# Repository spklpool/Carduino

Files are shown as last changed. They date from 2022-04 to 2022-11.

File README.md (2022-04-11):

# Carduino

This repository contains the source code for the Carduino library for Arduino IDE as well as design files for the electronics and the 3d printed enclosure for the Carduino device.  Each of these 3 components will be desctibed separately below.  More information about Carduino can be found at https://carduino.co

Everything you need to build a Carduino is in this repository if you have the necessary equipment.  If you are so inclined, you scan shop around for all the parts and build one yourself using the information you find in here.  You can also order a kit with all the electronic parts from our store at
https://www.tindie.com/stores/Sparkle/

There, you can also order one fully assembled and tested, including the 3d printed enclosure and a USB cable for close to the same price it would cost you to buy all the individual parts and the shipping costs.  Also, buying from our store helps support the continuing development of the project.  We have other things in the works you might like if you're interested in Cardano and electronics.

## Arduino library
The Arduino IDE can be downloaded here:
https://www.arduino.cc/en/software
The files that make up the library are under the src folder for reference if you want to look at the code.  To use it though, you'll want to install it as a library in the IDE.  Instructions for installing the library and everything else you need to program your Carduino can be found in this tutorial video:
https://www.youtube.com/watch?v=BPkC6jxjeJc&t=7s

## PCB design files
The PCB is designed using Eagle.  It meets the criteria for being edited using the free edition for personal use, which can be downloaded here:
https://www.autodesk.ca/en/products/eagle/free-download
The PCB design files can be found in the eagle folder.
The parts list with recommended manufacturer part numbers is available in the [parts file](eagle/parts.md)

## Enclosure 3d model
The enclosure was designed with TinkerCad.  Unfortunately, TimcarCad does not support saving the native files, but the exported .stl files can be imported and tweaked as you wish at:
https://www.tinkercad.com/
The 3d model files can be found in the model folder.

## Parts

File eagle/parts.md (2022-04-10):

| Component | Manufacturer Part # | Count |
| --- | --- | ----- |
| USB Connector | 10118194-0011LF | 1 |
| USB to Serial | 428-203591-MG01 | 1 |
| Realtime Clock | RV-3028-C7 32.768kHz 1ppm | 1 |
| Battery Holder | BAT-HLD-012-SMT | 1 |
| Microprocessor | ATTINY804-SSF | 1 |
| Shift Register | SN74HCS596DR | 4 |
| Display LEDs | IN-P32AT5UW |  30 |
| Rx/Tx LEDs | 150080VS75000 | 2 |
| 1K Resistors | CR1206-JW-472ELF |  34 |
| 4.7 uF Capacitor | 791-0805B475M160CT | 1 |

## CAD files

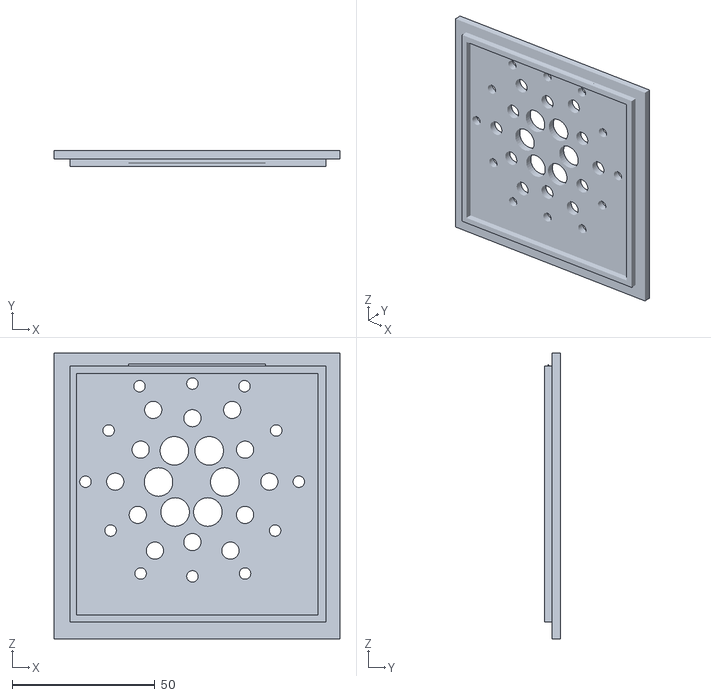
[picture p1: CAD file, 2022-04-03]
model/CarduinoFace.stl
100.0 x 5.70 x 100.0

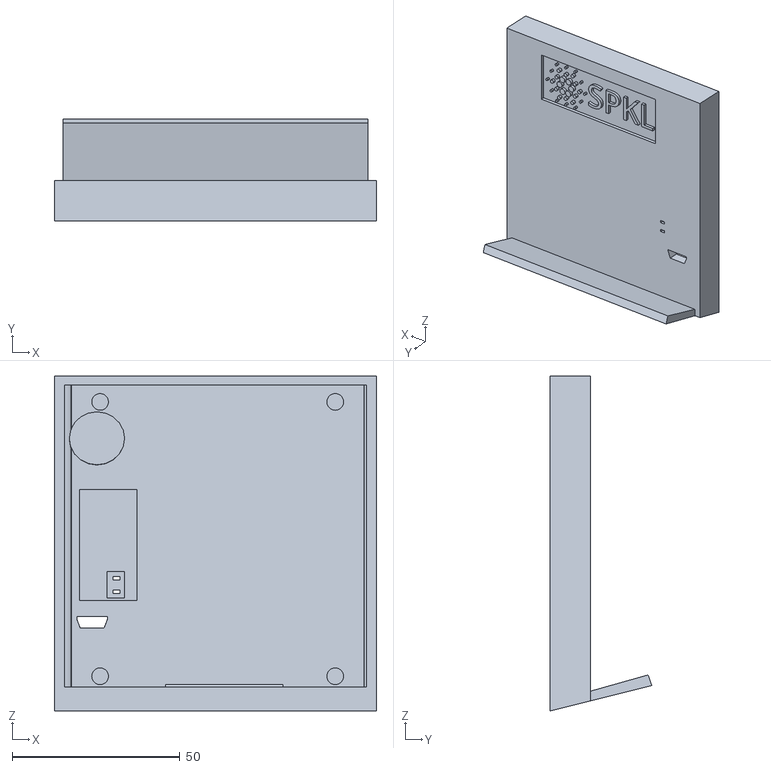
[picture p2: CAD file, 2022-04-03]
model/CarduinoBackWithLogo.stl
96.0 x 30.3 x 99.8

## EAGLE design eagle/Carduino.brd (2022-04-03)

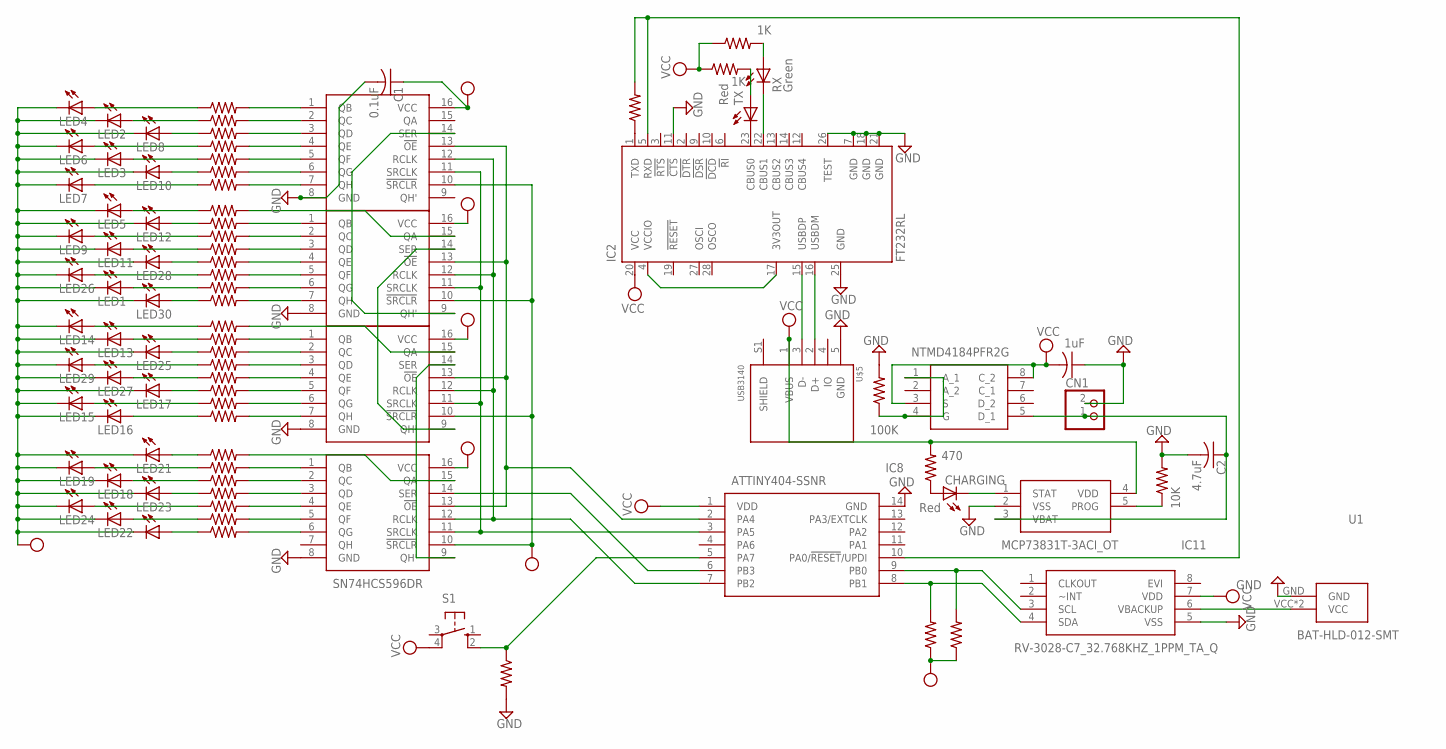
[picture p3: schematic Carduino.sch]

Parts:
C1: 0.1uF; C1206
C2: 4.7uF; C1206
C3: 1uF; C1206
CHARGING: Red; CHIP-LED0805
CN1: JST_2PIN-SMT-RA; JST-PH-2-SMT-RA
IC2: FT232RL; SSOP28
IC3, IC4, IC5, IC6: SN74HCS596DR; SOIC127P600X175-16N
IC7: NTMD4184PFR2G; SOIC127P600X175-8N
IC8: ATTINY404-SSNR; SOIC127P600X175-14N
IC9: MCP73831T-3ACI_OT; SOT95P270X145-5N
IC11: RV-3028-C7_32.768KHZ_1PPM_TA_Q; RV3028C732768KHZ1PPMTAQC
LED1, LED2, LED3, LED4, LED5, LED6, LED7, LED8, LED9, LED10, LED11, LED12, LED13, LED14, LED15, LED16, LED17, LED18, LED19, LED20, LED21, LED22, LED23, LED24, LED25, LED26, LED27, LED28, LED29, LED30: LUXEON2835L128-1890NA3500001; LUXEON2835
R1, R16: 470; R0805
R2, R3, R7, R8, R9, R10, R11, R12, R13, R14, R15, R17, R18, R19, R20, R31, R32, R33, R34, R35, R36, R37, R38, R39, R40, R41, R42, R43, R44, R45, R46, R47: 1K; R0805
R4, R5, R6: 4.7K; R0805
R21: 100K; R0805
R22: 10K; R0805
RX: Green; CHIP-LED0805
S1: 40-XX-ROUND; B3F-40XX-ROUND
TX: Red; CHIP-LED0805
U1: BAT-HLD-012-SMT; BATHLD012SMT
U$5: USB3140; USB3140-30-0170-0-C

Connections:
GND: C1.2, C2.2, C3.1, CN1.2 (1), IC2.7 (GND), IC2.11 (!CTS), IC2.18 (GND), IC2.21 (GND), IC2.25 (GND), IC2.26 (TEST), IC3.8 (GND), IC4.8 (GND), IC5.8 (GND), IC6.8 (GND), IC8.14 (GND), IC9.2 (VSS), IC11.5 (VSS), R6.2, R21.2, R22.2, U1.GND, U$5.5 (GND)
unnamed: LED4.ANODE (A), R15.1
unnamed: LED2.ANODE (A), R14.1
unnamed: LED8.ANODE (A), R13.1
unnamed: LED6.ANODE (A), R12.1
unnamed: LED3.ANODE (A), R11.1
unnamed: LED12.ANODE (A), R7.1
unnamed: LED7.ANODE (A), R9.1
unnamed: LED5.ANODE (A), R8.1
unnamed: LED10.ANODE (A), R10.1
unnamed: LED9.ANODE (A), R17.1
unnamed: LED11.ANODE (A), R18.1
unnamed: LED28.ANODE (A), R19.1
unnamed: LED26.ANODE (A), R20.1
unnamed: LED1.ANODE (A), R31.1
unnamed: LED30.ANODE (A), R32.1
unnamed: LED14.ANODE (A), R33.1
unnamed: LED13.ANODE (A), R34.1
unnamed: LED25.ANODE (A), R35.1
unnamed: LED29.ANODE (A), R36.1
unnamed: LED27.ANODE (A), R37.1
unnamed: LED17.ANODE (A), R38.1
unnamed: LED15.ANODE (A), R39.1
unnamed: LED16.ANODE (A), R40.1
unnamed: LED21.ANODE (A), R41.1
unnamed: LED19.ANODE (A), R42.1
unnamed: LED18.ANODE (A), R43.1
unnamed: LED23.ANODE (A), R44.1
unnamed: LED24.ANODE (A), R45.1
unnamed: LED22.ANODE (A), R46.1
unnamed: LED20.ANODE (A), R47.1
unnamed: IC8.8 (PB1), IC11.4 (SDA), R4.2
unnamed: IC8.9 (PB0), IC11.3 (SCL), R5.2
unnamed: IC11.6 (VBACKUP), U1.VCC, U1.VCC2 (VCC)
unnamed: IC8.5 (PA7), R6.1, S1.2 (S1)
unnamed: IC3.13 (!OE), IC4.13 (!OE), IC5.13 (!OE), IC6.13 (!OE), IC8.2 (PA4)
unnamed: IC7.1 (A_1), IC7.4 (G), R21.1
unnamed: IC9.5 (PROG), R22.1
unnamed: C2.1, CN1.1 (2), IC7.5 (D_1), IC9.3 (VBAT)
unnamed: CHARGING.C, IC9.1 (STAT)
unnamed: CHARGING.A, R16.1
unnamed: IC3.1 (QB), R15.2
unnamed: IC3.2 (QC), R14.2
unnamed: IC3.3 (QD), R13.2
unnamed: IC3.4 (QE), R12.2
unnamed: IC3.5 (QF), R11.2
unnamed: IC3.6 (QG), R10.2
unnamed: IC3.7 (QH), R9.2
unnamed: IC4.15 (QA), R8.2
unnamed: IC4.1 (QB), R7.2
unnamed: IC4.2 (QC), R17.2
unnamed: IC4.3 (QD), R18.2
unnamed: IC4.4 (QE), R19.2
unnamed: IC4.5 (QF), R20.2
unnamed: IC4.6 (QG), R31.2
unnamed: IC4.7 (QH), R32.2
unnamed: IC5.15 (QA), R33.2
unnamed: IC5.1 (QB), R34.2
unnamed: IC5.2 (QC), R35.2
unnamed: IC5.3 (QD), R36.2
unnamed: IC5.4 (QE), R37.2
unnamed: IC5.5 (QF), R38.2
unnamed: IC5.6 (QG), R39.2
unnamed: IC5.7 (QH), R40.2
unnamed: IC6.6 (QG), R47.2
unnamed: IC6.5 (QF), R46.2
unnamed: IC6.4 (QE), R45.2
unnamed: IC6.3 (QD), R44.2
unnamed: IC6.2 (QC), R43.2
unnamed: IC6.1 (QB), R42.2
unnamed: IC6.15 (QA), R41.2
unnamed: IC5.14 (SER), IC6.9 (QH')
unnamed: IC4.14 (SER), IC5.9 (QH')
unnamed: IC3.14 (SER), IC4.9 (QH')
unnamed: IC3.11 (SRCLK), IC4.11 (SRCLK), IC5.11 (SRCLK), IC6.11 (SRCLK), IC8.3 (PA5)
unnamed: IC3.12 (RCLK), IC4.12 (RCLK), IC5.12 (RCLK), IC6.12 (RCLK), IC8.7 (PB2)
unnamed: IC6.14 (SER), IC8.6 (PB3)
unnamed: IC2.16 (USBDM), U$5.2 (D+)
unnamed: IC2.15 (USBDP), U$5.3 (D-)
unnamed: IC2.4 (VCCIO), IC2.17 (3V3OUT)
unnamed: IC2.1 (TXD), R1.1
unnamed: IC2.5 (RXD), IC8.10 (PA0/!RESET!/UPDI), R1.2
unnamed: R2.2, RX.A
unnamed: R3.2, TX.A
unnamed: IC2.23 (CBUS0), TX.C
unnamed: IC2.22 (CBUS1), RX.C
VCC: C1.1, C3.2, IC2.20 (VCC), IC3.10 (!SRCLR), IC3.16 (VCC), IC4.10 (!SRCLR), IC4.16 (VCC), IC5.10 (!SRCLR), IC5.16 (VCC), IC6.10 (!SRCLR), IC6.16 (VCC), IC7.3 (S), IC7.8 (C_2), IC8.1 (VDD), IC9.4 (VDD), IC11.7 (VDD), LED1.CATHODE (C), LED2.CATHODE (C), LED3.CATHODE (C), LED4.CATHODE (C), LED5.CATHODE (C), LED6.CATHODE (C), LED7.CATHODE (C), LED8.CATHODE (C), LED9.CATHODE (C), LED10.CATHODE (C), LED11.CATHODE (C), LED12.CATHODE (C), LED13.CATHODE (C), LED14.CATHODE (C), LED15.CATHODE (C), LED16.CATHODE (C), LED17.CATHODE (C), LED18.CATHODE (C), LED19.CATHODE (C), LED20.CATHODE (C), LED21.CATHODE (C), LED22.CATHODE (C), LED23.CATHODE (C), LED24.CATHODE (C), LED25.CATHODE (C), LED26.CATHODE (C), LED27.CATHODE (C), LED28.CATHODE (C), LED29.CATHODE (C), LED30.CATHODE (C), R2.1, R3.1, R4.1, R5.1, R16.2, S1.4 (P1), U$5.1 (VBUS)

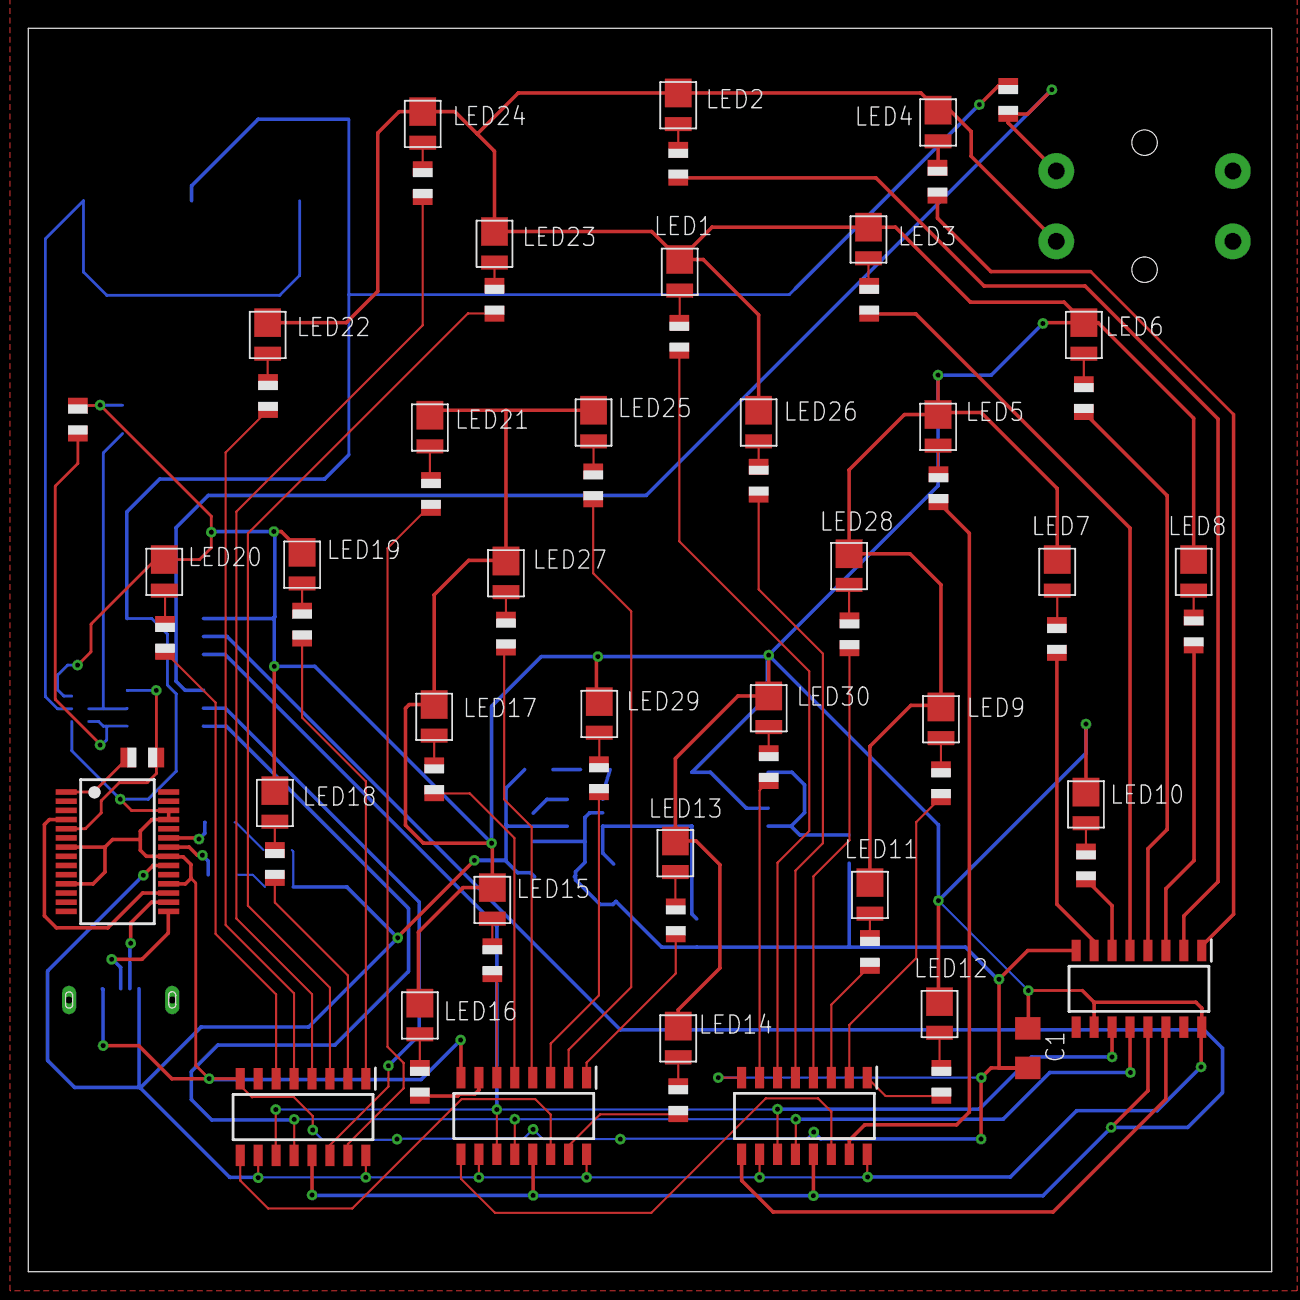
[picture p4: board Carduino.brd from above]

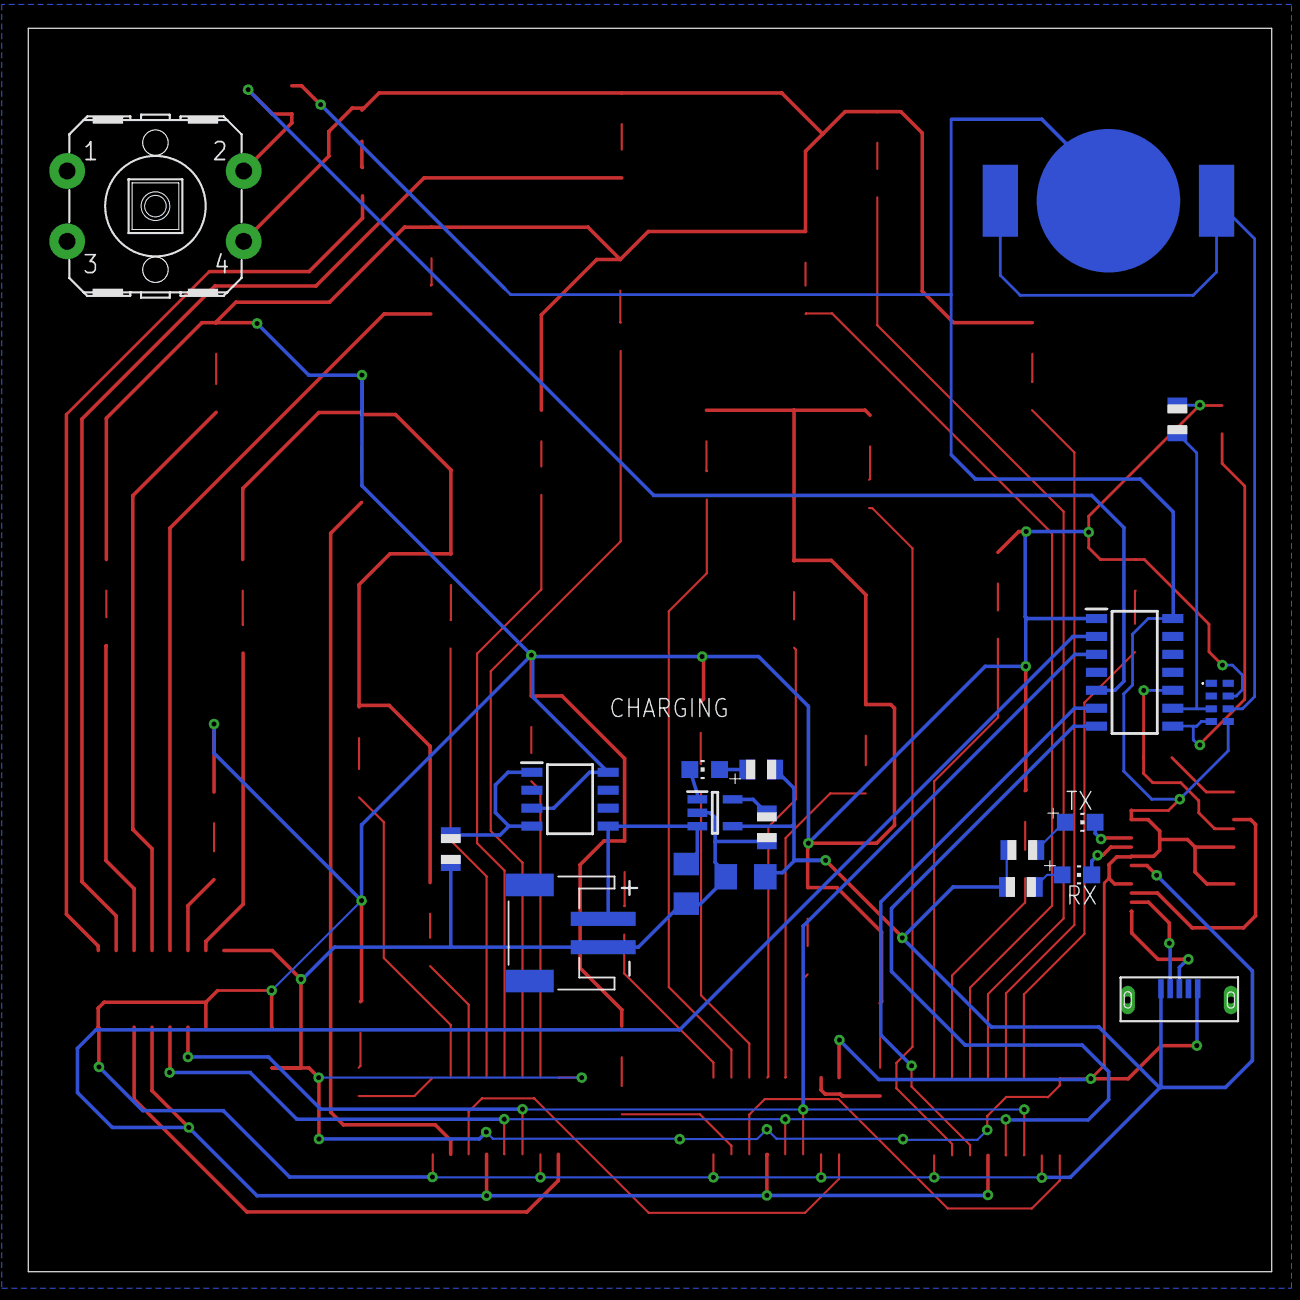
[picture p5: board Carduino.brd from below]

Board: 2 copper layers, 88.0 x 88.0 mm, 88 parts (19 on the bottom side), 87 nets.

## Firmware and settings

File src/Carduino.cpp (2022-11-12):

#include "Arduino.h"
#include "Carduino.h"

// functions copied from https://github.com/NorthernWidget/DS3231
// just took the minimal fuctionality we need for Carduino, which
// does not care about actual dates and times.  We just want a high
// precision number of seconds since a given start time to calculate
// epochs and fractions thereof.
static uint8_t bcd2bin (uint8_t val) { return val - 6 * (val >> 4); }
static const uint8_t daysInMonth [] PROGMEM = { 31,28,31,30,31,30,31,31,30,31,30,31 };
bool isleapYear(const uint8_t y) {
  if(y&3)//check if divisible by 4
    return false;
  //only check other, when first failed
  return (y % 100 || y % 400 == 0);
}
static uint16_t date2days(uint16_t y, uint8_t m, uint8_t d) {
    if (y >= 2000)
        y -= 2000;
    uint16_t days = d;
    for (uint8_t i = 1; i < m; ++i)
        days += pgm_read_byte(daysInMonth + i - 1);
    if (m > 2 && isleapYear(y))
        ++days;
    return days + DAYS_IN_YEAR * y + (y + 3) / 4 - 1;
}
static long time2long(uint16_t days, uint8_t h, uint8_t m, uint8_t s) {
    return ((days * 24L + h) * 60 + m) * 60 + s;
}
byte Carduino::decToBcd(byte val) {
  return ( (val/10*16) + (val%10) );
}
byte Carduino::bcdToDec(byte val) {
  return ( (val/16*10) + (val%16) );
}
// end of copied functions


Carduino::Carduino() {
  pinMode(clockPin, OUTPUT);
  pinMode(dataPin, OUTPUT);
  pinMode(latchPin, OUTPUT);
  pinMode(buttonPin, INPUT);
  pinMode(oePin, OUTPUT);
  Wire.begin();
}

void Carduino::init() {
  if (isRV3028Clock()) {
    if (!isRV3028Configured()) {
      RV3028Configure();
      configuringConfirmationDisplay();
    }
  }
}

void Carduino::setBrightness(byte brightness) // 0 to 255
{
  analogWrite(oePin, 255-brightness);
}

void Carduino::displayHoursAndMinutes() {
  uint16_t y;
  uint8_t m, d, hh, mm, ss;
  
  getNowFromClock(y,  m, d, hh, mm, ss);

  uint32_t hoursArray[] = { dot2, dot4, dot6, dot8, 
                            dot10, dot12, dot14, dot16,
                            dot18, dot20, dot22, dot24 };

  uint32_t minutesArray2[] = { dot1, dot3, dot5, dot7, 
                               dot9, dot11, dot13, dot15,
                               dot17, dot19, dot21, dot23 };

  uint32_t minutesArray1[] = { dot25, dot26, dot28, dot30, dot29, dot27 };
  
  displayDots(hoursArray[hh%12] & minutesArray1[mm/10] & minutesArray2[mm%10]);

// uncomment to debug on a device that supports it
//  char dateTimeString[60];
//  sprintf(dateTimeString, "hh mod 12: %i mm/10: %i mm mod 10: %i", hh%12, mm/10, mm%10);
//  Serial.println(dateTimeString);

  delay(1000);
}

void Carduino::runClock() {
  runClock(1, false);
}

void Carduino::runClock(bool middleEpochCounter) {
  runClock(1, middleEpochCounter);
}

void Carduino::runClock(uint32_t speedMultiplier) {
  runClock(speedMultiplier, false);
}

void Carduino::runClock(uint32_t speedMultiplier, bool middleEpochCounter) {
  
  const int sizeofClockarray = 30;
  uint32_t clockarray[sizeofClockarray] = { dot1, dot2, dot3, dot4, dot5, dot6, dot7, dot8,
                                            dot9, dot10, dot11, dot12, dot13, dot14, dot15, dot16,
                                            dot17, dot18, dot19, dot20, dot21, dot22, dot23, dot24,
                                            dot25, dot26, dot27, dot28, dot29, dot30 };
  for (int i=0; i<sizeofClockarray; i++) {
    if (i>0) {
      clockarray[i] = clockarray[i] & clockarray[i-1];
    } 
  }
  
  unsigned long beginingOfTimeSeconds = getSecondsAtBeginingOfTime();
  unsigned long nowSeconds = getNowFromClock() - (BEGINING_OF_TIME_UTC_OFFSET * 3600);
  unsigned long shelley_seconds = nowSeconds - beginingOfTimeSeconds;
  unsigned long seconds_in_epoch = 432000; //60*60*5*24
  unsigned long seconds_in_this_epoch = shelley_seconds % seconds_in_epoch;
  float portion_of_epoch_completed = seconds_in_this_epoch / (float)seconds_in_epoch;
  int dot = portion_of_epoch_completed * 24;
  int epochIndex = seconds_in_this_epoch % 6;

  // was overflowing dynamic memory space with an array of middle dots
  // below implementation is uglier than using an array , but it trades
  // program space (which I have) with dynamic memory space (which I don't have)
  if (epochIndex == 0) {
    displayDots(clockarray[dot] & dot25);
  } else if (epochIndex == 1) {
    displayDots(clockarray[dot] & dot25 & dot26);
  } else if (epochIndex == 2) {
    displayDots(clockarray[dot] & dot25 & dot26 & dot28);
  } else if (epochIndex == 3) {
    displayDots(clockarray[dot] & dot25 & dot26 & dot28 & dot30);
  } else if (epochIndex == 4) {
    displayDots(clockarray[dot] & dot25 & dot26 & dot28 & dot30 & dot29);
  } else if (epochIndex == 5) {
    displayDots(clockarray[dot] & dot25 & dot26 & dot28 & dot30 & dot29 & dot27);
  }
  delay(100);
}

void Carduino::teaser() {
  delay(3000);
  accelleratingClock();
  reverseClock();
  fireworks1();
  sequence4();
  fireworks2();
  fireworks2();
  sequence2(50);
  sequence3(50);
  sequence2(50);
  full();
  fadeout();
}

void Carduino::configuringConfirmationDisplay() {
  const int sizeofClockarray = 30;
  uint32_t clockarray[sizeofClockarray] = { dot1, dot2, dot3, dot4, dot5, dot6, dot7, dot8,
                                            dot9, dot10, dot11, dot12, dot13, dot14, dot15, dot16,
                                            dot17, dot18, dot19, dot20, dot21, dot22, dot23, dot24,
                                            dot25, dot26, dot27, dot28, dot29, dot30 };

  for (int i=0; i<sizeofClockarray; i++) {
    if (i>0) {
      clockarray[i] = clockarray[i] & clockarray[i-1];
    } 
  }
                                            
  for (int i=0; i<sizeofClockarray; i++) {
    displayDots(clockarray[i]);
    delay(200);
  }
}

void Carduino::sequence1() {
  const int sizeofClockarray = 30;
  uint32_t clockarray[sizeofClockarray] = { dot1, dot2, dot3, dot4, dot5, dot6, dot7, dot8,
                                            dot9, dot10, dot11, dot12, dot13, dot14, dot15, dot16,
                                            dot17, dot18, dot19, dot20, dot21, dot22, dot23, dot24,
                                            dot25, dot26, dot27, dot28, dot29, dot30 };
  for (int i=0; i<sizeofClockarray; i++) {
    displayDots(clockarray[i]);
    delay(300);
  }
}

void Carduino::sequence4() {
  const int sizeofClockarray = 30;
  uint32_t clockarray[sizeofClockarray] = { dot1, dot2, dot3, dot4, dot5, dot6, dot7, dot8,
                                            dot9, dot10, dot11, dot12, dot13, dot14, dot15, dot16,
                                            dot17, dot18, dot19, dot20, dot21, dot22, dot23, dot24,
                                            dot25, dot26, dot27, dot28, dot29, dot30 };
  for (int i=0; i<sizeofClockarray; i++) {
    displayDots(clockarray[i]);
    delay(50);
  }
}
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

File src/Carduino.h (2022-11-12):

#ifndef Carduino_h
#define Carduino_h

#include <Wire.h>

#define DS3231_ADDR                 0x68
#define RV3028_ADDR                 0x52


// These binary values are the secret sauce that makes this code simple.
// Each bit of the 32 bit entries in the array represents one
// of the output pins on one of the 4 shift registers.
// Below is a represendation of the bits grouped by the shift
// registers.  Each group of 8 bits is serialized least significant
// bit first and the shift registers are daisy chained so the right 
// most bits in the array will end up being latched on shift register
// 1 after all bits are serialized.
// 44444444333333332222222211111111

// 20 23     21 24 19 22 15 18 17 16 30 14 9  12 11 10 7 2 5 8 3 6 4

//    1      13  

#define dot0  0b11111111111111111111111111111111
#define dot1  0b11111111111111111111110111111111
#define dot2  0b11111111111111111111111111011111
#define dot3  0b11111111111111111111111111111011
#define dot4  0b11111111111111111111111110111111
#define dot5  0b11111111111111110111111111111111
#define dot6  0b11111111111111111111111111110111
#define dot7  0b11111111111111111111111111111110
#define dot8  0b11111111111111111111111111101111
#define dot9  0b11111111111111111101111111111111
#define dot10 0b11111111111111111111111111111101
#define dot11 0b11111111111111111110111111111111
#define dot12 0b11111111111111111011111111111111
#define dot13 0b11111111101111111111111111111111
#define dot14 0b11111111011111111111111111111111
#define dot15 0b11111111111111011111111111111111
#define dot16 0b11111111111111101111111111111111
#define dot17 0b11111111111110111111111111111111
#define dot18 0b11011111111111111111111111111111
#define dot19 0b10111111111111111111111111111111
#define dot20 0b11111101111111111111111111111111
#define dot21 0b01111111111111111111111111111111
#define dot22 0b11111011111111111111111111111111
#define dot23 0b11101111111111111111111111111111
#define dot24 0b11110111111111111111111111111111
#define dot25 0b11111111110111111111111111111111
#define dot26 0b11111111111111111111101111111111
#define dot27 0b11111111111101111111111111111111
#define dot28 0b11111111111111111111011111111111
#define dot29 0b11111111111011111111111111111111
#define dot30 0b11111111111111111111111011111111

#define ALLOFF 0b01111111111111111111111111111111
#define ALLON  0b00000000000000000000000000000000

#define oePin 0
#define clockPin 1
#define buttonPin 3
#define dataPin 4
#define latchPin 5

#define DAYS_IN_YEAR 365
#define CARDUINO_LED_COUNT 32
#define HOURS_TO_SECONDS_MULTIPLIER 3600
#define SECONDS_IN_DOT 18000 // 60*60*5;
#define DOTS_IN_EPOCH 24
#define MILLIS_IN_SECOND 1000
#define RESET_CYCLE_THRESHOLD 50
#define ADVANCE_CYCLE_THRESHOLD 10

// begining of time in UTC
#define BEGINING_OF_TIME_UTC_OFFSET -5
#define BEGINING_OF_TIME_HOURS 21
#define BEGINING_OF_TIME_MINUTES 45
#define BEGINING_OF_TIME_SECONDS 00
#define BEGINING_OF_TIME_DAY 3
#define BEGINING_OF_TIME_MONTH 8
#define BEGINING_OF_TIME_YEAR 20
#define SHELLY_EPOCH_OFFSET 209;

class Carduino
{
  public:
    Carduino();
    void init();
    bool isDS3231Clock();
    bool isRV3028Clock();
    void setBrightness(byte brightness);
    void displayHoursAndMinutes();
    void runClock();
    void runClock(bool middleEpochCounter);
    void runClock(uint32_t speedMultiplier);
    void runClock(uint32_t speedMultiplier, bool middleEpochCounter);
    void teaser();
    void inwardSpiral();
    void displayDots(uint32_t data);
    void setTimeToNow();
    void checkDateTime();
    void printNow();
    long getSecondsAtBeginingOfTime();
    long getSecondsFormYMDHHMMSS(uint16_t y, uint8_t m, uint8_t d, uint8_t hh, uint8_t mm, uint8_t ss);
    long getNowFromClock();
    void getNowFromClock(uint16_t &y, uint8_t &m, uint8_t &d, uint8_t &hh, uint8_t &mm, uint8_t &ss);
    void resetClockToZero();
    void setClock(const char* date, const char* time);
    void setClockToSeconds(long timeInSeconds);    
    void setClockToYMDHMS(uint16_t y, uint8_t m, uint8_t d, uint8_t hh, uint8_t mm, uint8_t ss);
    void advanceClockByOneDot();
    bool isButtonPressed();
    void full();
    void heartbeat();
    void fadeout();
    void fireworks1();
    void fireworks2();
    void sequence1();
    void sequence2(int limit);
    void sequence3(int limit);
    void sequence4();
    void accelleratingClock();
    void accelleratingClock2();
    void reverseClock();
    void configuringConfirmationDisplay();
    bool isRV3028Configured();
    void RV3028Configure();
    
  private:
    
    byte decToBcd(byte val);
    byte bcdToDec(byte val);
    uint32_t dotsElapsed = 0;
    uint32_t epochsElapsed = 0;
    uint8_t getValueAtIndex(uint32_t data, byte index);
    uint8_t resetCycleCount = 0;
    uint8_t advanceCycleCount = 0;
    bool buttonPressed = false;
    void setRV3028ToYMDHMS(uint16_t y, uint8_t m, uint8_t d, uint8_t hh, uint8_t mm, uint8_t ss);
    void setDS3231ToYMDHMS(uint16_t y, uint8_t m, uint8_t d, uint8_t hh, uint8_t mm, uint8_t ss);
    long getNowFromDS3231();
    void getNowFromDS3231Clock(uint16_t &y, uint8_t &m, uint8_t &d, uint8_t &hh, uint8_t &mm, uint8_t &ss);
    long getNowFromRV3028();
    void getNowFromRV3028Clock(uint16_t &y, uint8_t &m, uint8_t &d, uint8_t &hh, uint8_t &mm, uint8_t &ss);
    void printDateTimeToSerial(uint8_t ss, uint8_t mm, uint8_t hh, uint8_t d, uint8_t m, uint16_t y);
    void Carduino::RV3028waitForNotBusy();
    uint8_t RV3028readRegister(uint8_t addr);
    uint8_t RV3028readConfigEEPROM(uint8_t eepromaddr);
    void RV3028writeConfigEEPROM(uint8_t eepromaddr, uint8_t val);
    void RV3028disableAutoRefresh();
    void RV3028enableAutoRefresh();
    void RV3028writeToEEPROM();
};


#endif

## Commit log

2021-12-21 addin eagle files
    [Carduino.brd, Carduino.sch]
2021-12-23 added logo and moved USB port
    [Carduino.brd, Carduino.sch]
2022-01-03 added realtime clock
    [Carduino.brd, Carduino.sch]
2022-01-14 better use of button to adjust dots
    [Carduino.brd, Carduino.sch]
2022-02-12 preparing for 1.1 release
    [Carduino.brd]
2022-03-06 removing dimensions that got into the board
    [Carduino.brd]
2022-03-06 oe pin and teaser eye candy
2022-03-06 enclosure 3d model files
    [CarduinoBackWithLogo.stl, CarduinoFace.stl]
2022-03-18 more sturdy model
    [CarduinoBackWithLogo.stl, CarduinoFace.stl]
2022-04-03 make enclosure less fragile
    [CarduinoBackWithLogo.stl, CarduinoFace.stl]
2022-04-03 new clock and ftdi chips
    [Carduino.brd, Carduino.sch]
2022-04-04 adding missing capacitor to parts list
